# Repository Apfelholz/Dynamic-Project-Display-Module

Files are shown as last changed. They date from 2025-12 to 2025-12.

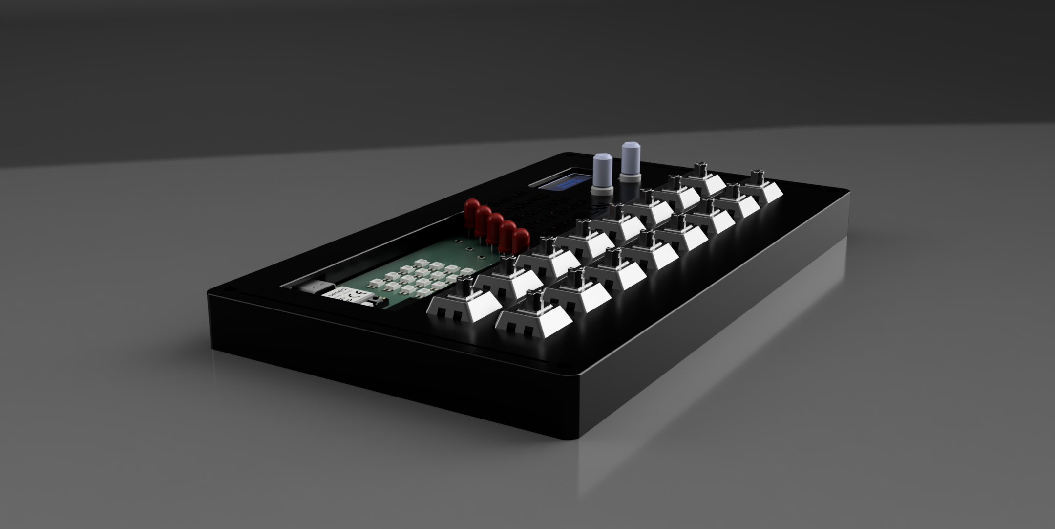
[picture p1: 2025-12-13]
CAD/Renders/DPDIM_V1_FrontLeft.png

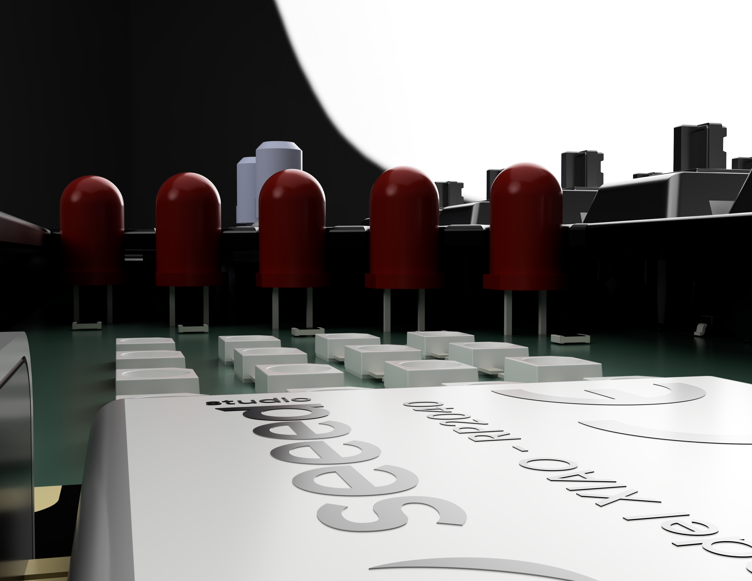
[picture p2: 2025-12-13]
CAD/Renders/DPDIM V1_Inside.png

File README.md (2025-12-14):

## Hi

I'm a young student from Germany who loves to program and also builds in the physical world from time to time. This project is the first time I ever worked on PCB design and produced a (serious) CAD model. 

When I found out about Blueprint I had already built an Arduino-based prototype of the idea that soon became this project. With the knollage of the requirements that I needed from this adventure I got to designing the DPDIM V1. (The first thing being finding some stupid acronym)

# Dynamic Project Display and Input Module

DPDIM is a 16-key micropad with a 4x4 RGB LED matrix, five status LEDs, an OLED display and two rotary encoders. It is based on the Seeed XIAO RP2040 and misuses KMK for the firmware.

## Features

- 16 keys for custom functionality
- 4x4 WS2812B RGB LED matrix as a simple and bright display option
- 128x32 OLED display
- 2 EC11 rotary encoders to get even more input options
- 5 status LEDs to get myself to do my work...

# CAD

The model includes a cutout for the USB and I2C connection in the back as well as a big one at the top to show some of the inside and the LED matrix. In the top plate there are also two decorative channels and the descriptions of the status LEDs. The keys are placed at the bottom for easy access when placed over the mouse on the desk. 

DPDIM V1_Inside

DPDIM_V1_FrontLeft

DPDIM_V1_FrontTop

The model has been made in Fusion 360 after Onshape did collapse on me. 

# PCB

The PCB design I did in KiCad while learning the software on the fly. The silkscreen picture is an experiment I don't expect to work but took the chance to test. 

Schematic: 

WhatsApp Bild 2025-12-07 um 17.29.00_7e5e3bc0

PCB:

WhatsApp Bild 2025-12-07 um 17.28.47_4aa92623

# Firmware

The firmware implements a JSON API that is able to be controlled from the PC. As I don't have the pad yet it is untested. 

The exact API layout:

### 1. LED Control

Control individual status LEDs.

**Command:**
```json
{
  "type": "led",
  "index": 0,
  "value": true
}
```

**Parameters:**
- `type` (string): `"led"`
- `index` (integer): LED index
- `value` (boolean): `true` = ON, `false` = OFF

### 2. RGB Pixel Control (Single)

**Command:**
```json
{
  "type": "rgb",
  "index": 5,
  "r": 255,
  "g": 128,
  "b": 0
}
```

**Parameters:**
- `type` (string): `"rgb"`
- `index` (integer): Pixel index
- `r` (integer)
- `g` (integer)
- `b` (integer)

### 3. RGB Pixel Control (All)

**Command:**
```json
{
  "type": "rgb_all",
  "r": 255,
  "g": 0,
  "b": 0
}
```

**Parameters:**
- `type` (string): `"rgb_all"`
- `r` (integer)
- `g` (integer)
- `b` (integer)

### 4. OLED Display - Set Text

**Command:**
```json
{
  "type": "oled",
  "line": 0,
  "text": "Hello World"
}
```

**Parameters:**
- `type` (string): `"oled"`
- `line` (integer): Line index
- `text` (string)

### 5. OLED Display - Clear All

**Command:**
```json
{
  "type": "oled_clear"
}
```

**Parameters:**
- `type` (string): `"oled_clear"`

## Events (Device → Host)

### 1. Key Press/Release

**Message:**
```json
{
  "type": "key",
  "row": 0,
  "col": 5,
  "state": "press"
}
```

**Fields:**
- `type` (string): `"key"`
- `row` (integer): Row index (0-1)
- `col` (integer): Column index (0-8)
- `state` (string): `"press"` or `"release"`

---

### 2. Encoder Rotation

**Message:**
```json
{
  "type": "encoder",
  "id": 0,
  "delta": 1
}
```

**Fields:**
- `type` (string): `"encoder"`
- `id` (integer)
- `delta` (integer): Direction: `1` = clockwise, `-1` = counter-clockwise

### 3. Encoder Button

**Message:**
```json
{
  "type": "encoder_btn",
  "id": 0,
  "state": "press"
}
```

**Fields:**
- `type` (string): `"encoder_btn"`
- `id` (integer)
- `state` (string): `"press"` or `"release"`

## Response Types

### Acknowledgment (ACK)

Sent when a command is successfully executed.

**Format:**
```json
{
  "type": "ack",
  "cmd": "led"
}
```

**Fields:**
- `type` (string): `"ack"`
- `cmd` (string): The command type that was executed

### Error

Sent when a command fails.

**Format:**
```json
{
  "type": "err",
  "cmd": "rgb",
  "reason": "bad_args"
}
```

**Fields:**
- `type` (string): `"err"`
- `cmd` (string): The command type that failed
- `reason` (string): Error reason:
  - `"json"` - JSON parsing error
  - `"bad_args"` - Invalid arguments or out-of-range values
  - `"unknown_cmd"` - Unknown command type

# BOM 

In BOM.csv

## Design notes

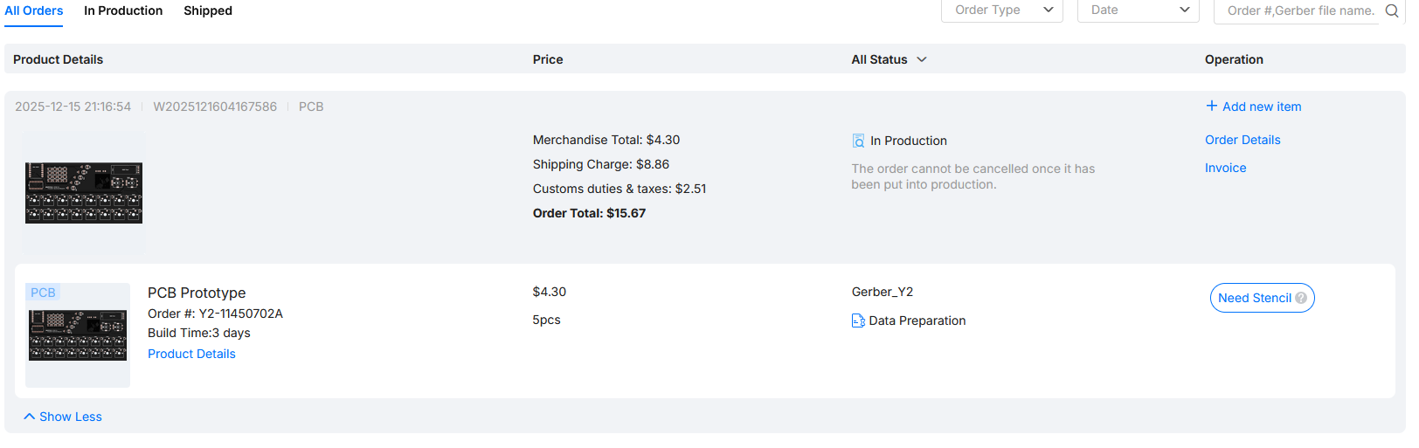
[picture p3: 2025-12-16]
JLCPCB.png

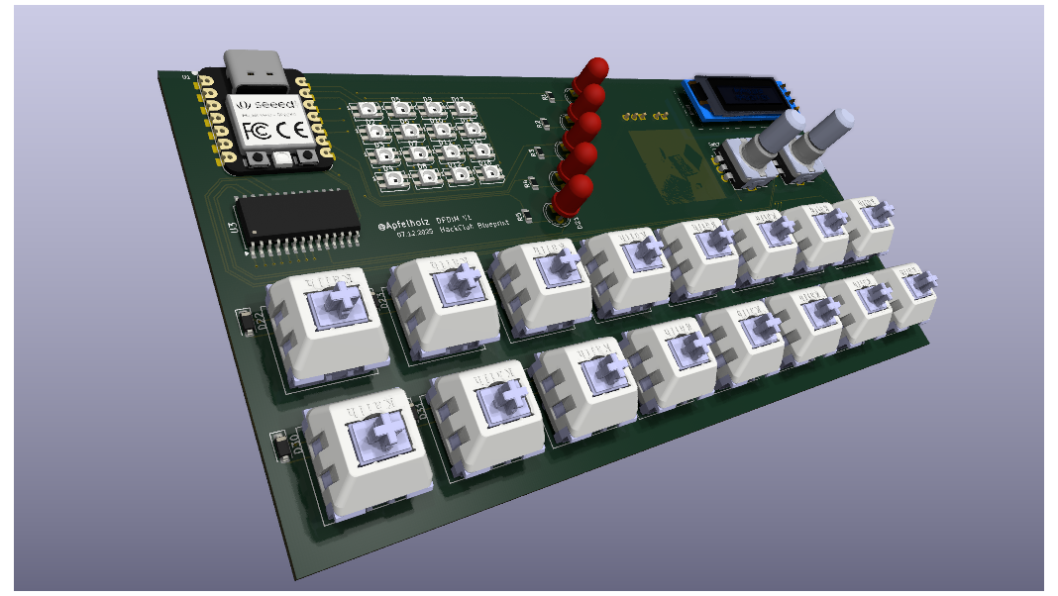
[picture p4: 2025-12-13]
CAD/Renders/KiCad-Diynamic-Project-Display-Module.png

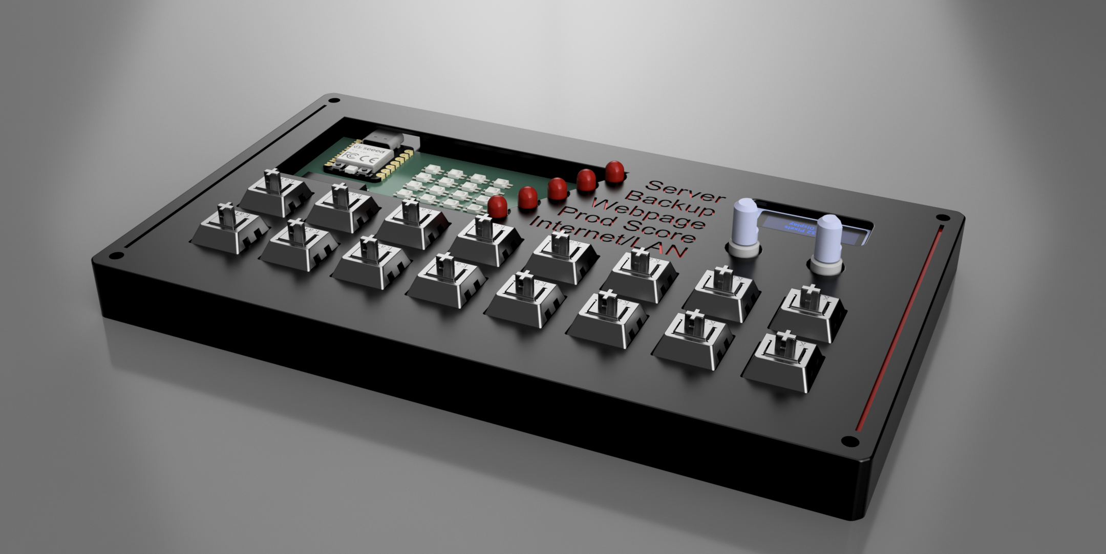
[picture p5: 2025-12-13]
CAD/Renders/DPDIM V1_FrontRight.png

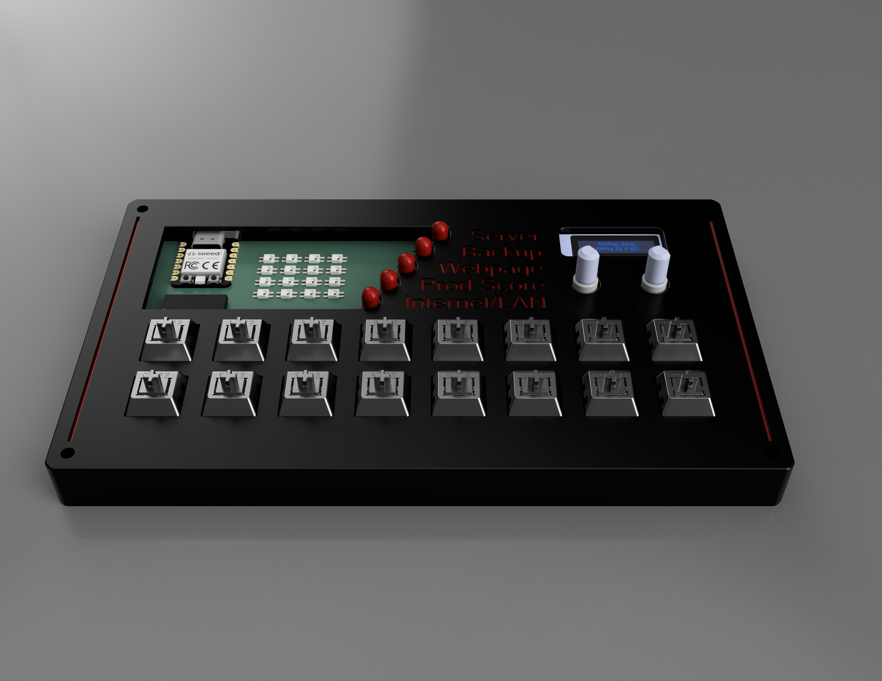
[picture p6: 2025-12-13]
CAD/Renders/DPDIM_V1_FrontTop.png

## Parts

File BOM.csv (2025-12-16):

KICad BOM
ID | Bezeichner | Footprint | Stückzahl | Bezeichnung | Link | Unit Price (€) | Total Price (€)
1 | R5,R3,R4,R1,R2 | R_0805_2012Metric_Pad1.20x1.40mm_HandSolder | 5 | 200R | https://de.aliexpress.com/item/1005003413960273.html?curPageLogUid=BFyG77zEiabK | - | 4,04
2 | SW3,SW6,SW2,SW16,SW10,SW14,SW12,SW8,SW7,SW5,SW13,SW9,SW4,SW11,SW1,SW15 | SW_Cherry_MX_1.00u_PCB | 16 | SW_Push | https://www.reichelt.de/de/de/shop/produkt/cherry_mx_blue_-_tastenmodul_-_fixierzapfen-369269 | provided
3 | D37,D24,D34,D28,D31,D22,D23,D32,D30,D27,D39,D33,D35,D29,D26,D36,D25,D38 | D_SOD-123 | 18 | D | https://de.aliexpress.com/item/1005007118972345.html?curPageLogUid=9GncDW1vCwrk | - | 3,64
4 | D9,D12,D1,D13,D2,D14,D8,D16,D3,D11,D15,D5,D7,D4,D10,D6 | LED_SK6812MINI_PLCC4_3.5x3.5mm_P1.75mm | 16 | SK6812MINI | https://de.aliexpress.com/item/1005007863635868.html?curPageLogUid=uiXVLImmVGYQ | provided
6 | Brd1 | SSD1306-0.91-OLED-4pin-128x32 | 1 | GME12864_OLED | https://de.aliexpress.com/item/1005008640108394.html?curPageLogUid=75kDP72p1P9Y | provided
7 | U1 | XIAO-RP2040-DIP | 1 | XIAO-RP2040-DIP | https://de.aliexpress.com/item/1005003683887126.html?curPageLogUid=iyNb21ibwtPA | provided
8 | SW17,SW18 | RotaryEncoder_Alps_EC11E-Switch_Vertical_H20mm_MountingHoles | 2 | RotaryEncoder_Switch_MP | https://de.aliexpress.com/item/1005008583446552.html?curPageLogUid=sLxNjNwPbA56 | provided
9 | U3 | SOIC-28W_7.5x17.9mm_P1.27mm | 1 | MCP23017_SO | https://de.aliexpress.com/item/1005009034247985.html?curPageLogUid=r1iDWc1KUoAc | - | 6,64
10 | J2 | PinHeader_1x02_P2.54mm_Horizontal | 1 | Conn_01x02_Pin | https://de.aliexpress.com/item/32963604292.html?curPageLogUid=C4FsHZ2x8Ltg | - | 0,99
11 | J1 | PinHeader_1x03_P2.54mm_Horizontal | 1 | Conn_01x03_Pin | https://de.aliexpress.com/item/32963604292.html?curPageLogUid=C4FsHZ2x8Ltg | - | 0,99
 |  |  | 4 | M3 14mm | https://www.aliexpress.com/ssr/300000512/BundleDeals2?productIds=1005005070119421:12000031519353305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 | provided
 |  |  | 4 | M3 4mmx5mm inserts | https://de.aliexpress.com/item/4000232858343.html?gatewayAdapt=usa2deu4itemAdapt | provided
 |  |  | 1 | PCB |  | 13,01 | 13,01
 |  |  | 16 | DSA keycaps |  | provided
 |  |  | 1 | USB Cabal | https://de.aliexpress.com/item/1005007431063094.html?mp=1 | 0,99 | 0,99
 |  |  |  |  |  | Total: | 30,3
 |  |  |  |  |  |  | 17,29

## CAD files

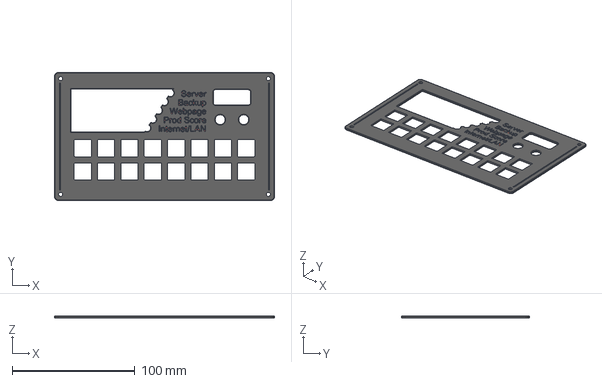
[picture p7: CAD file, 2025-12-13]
CAD/TopCase.step
179.5 x 104.4 x 1.50 mm

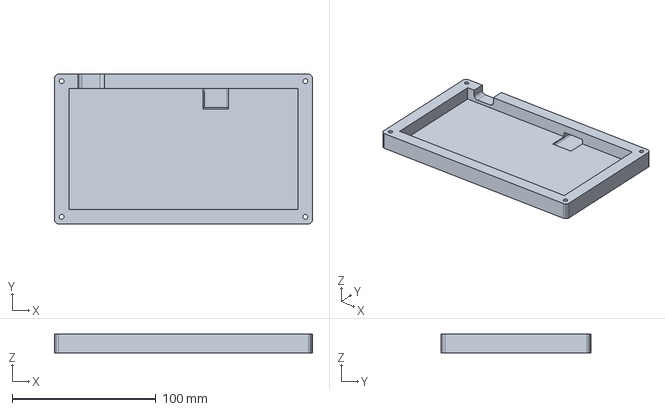
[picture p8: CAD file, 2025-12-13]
CAD/BottemCase.step
179.5 x 104.4 x 13.0 mm

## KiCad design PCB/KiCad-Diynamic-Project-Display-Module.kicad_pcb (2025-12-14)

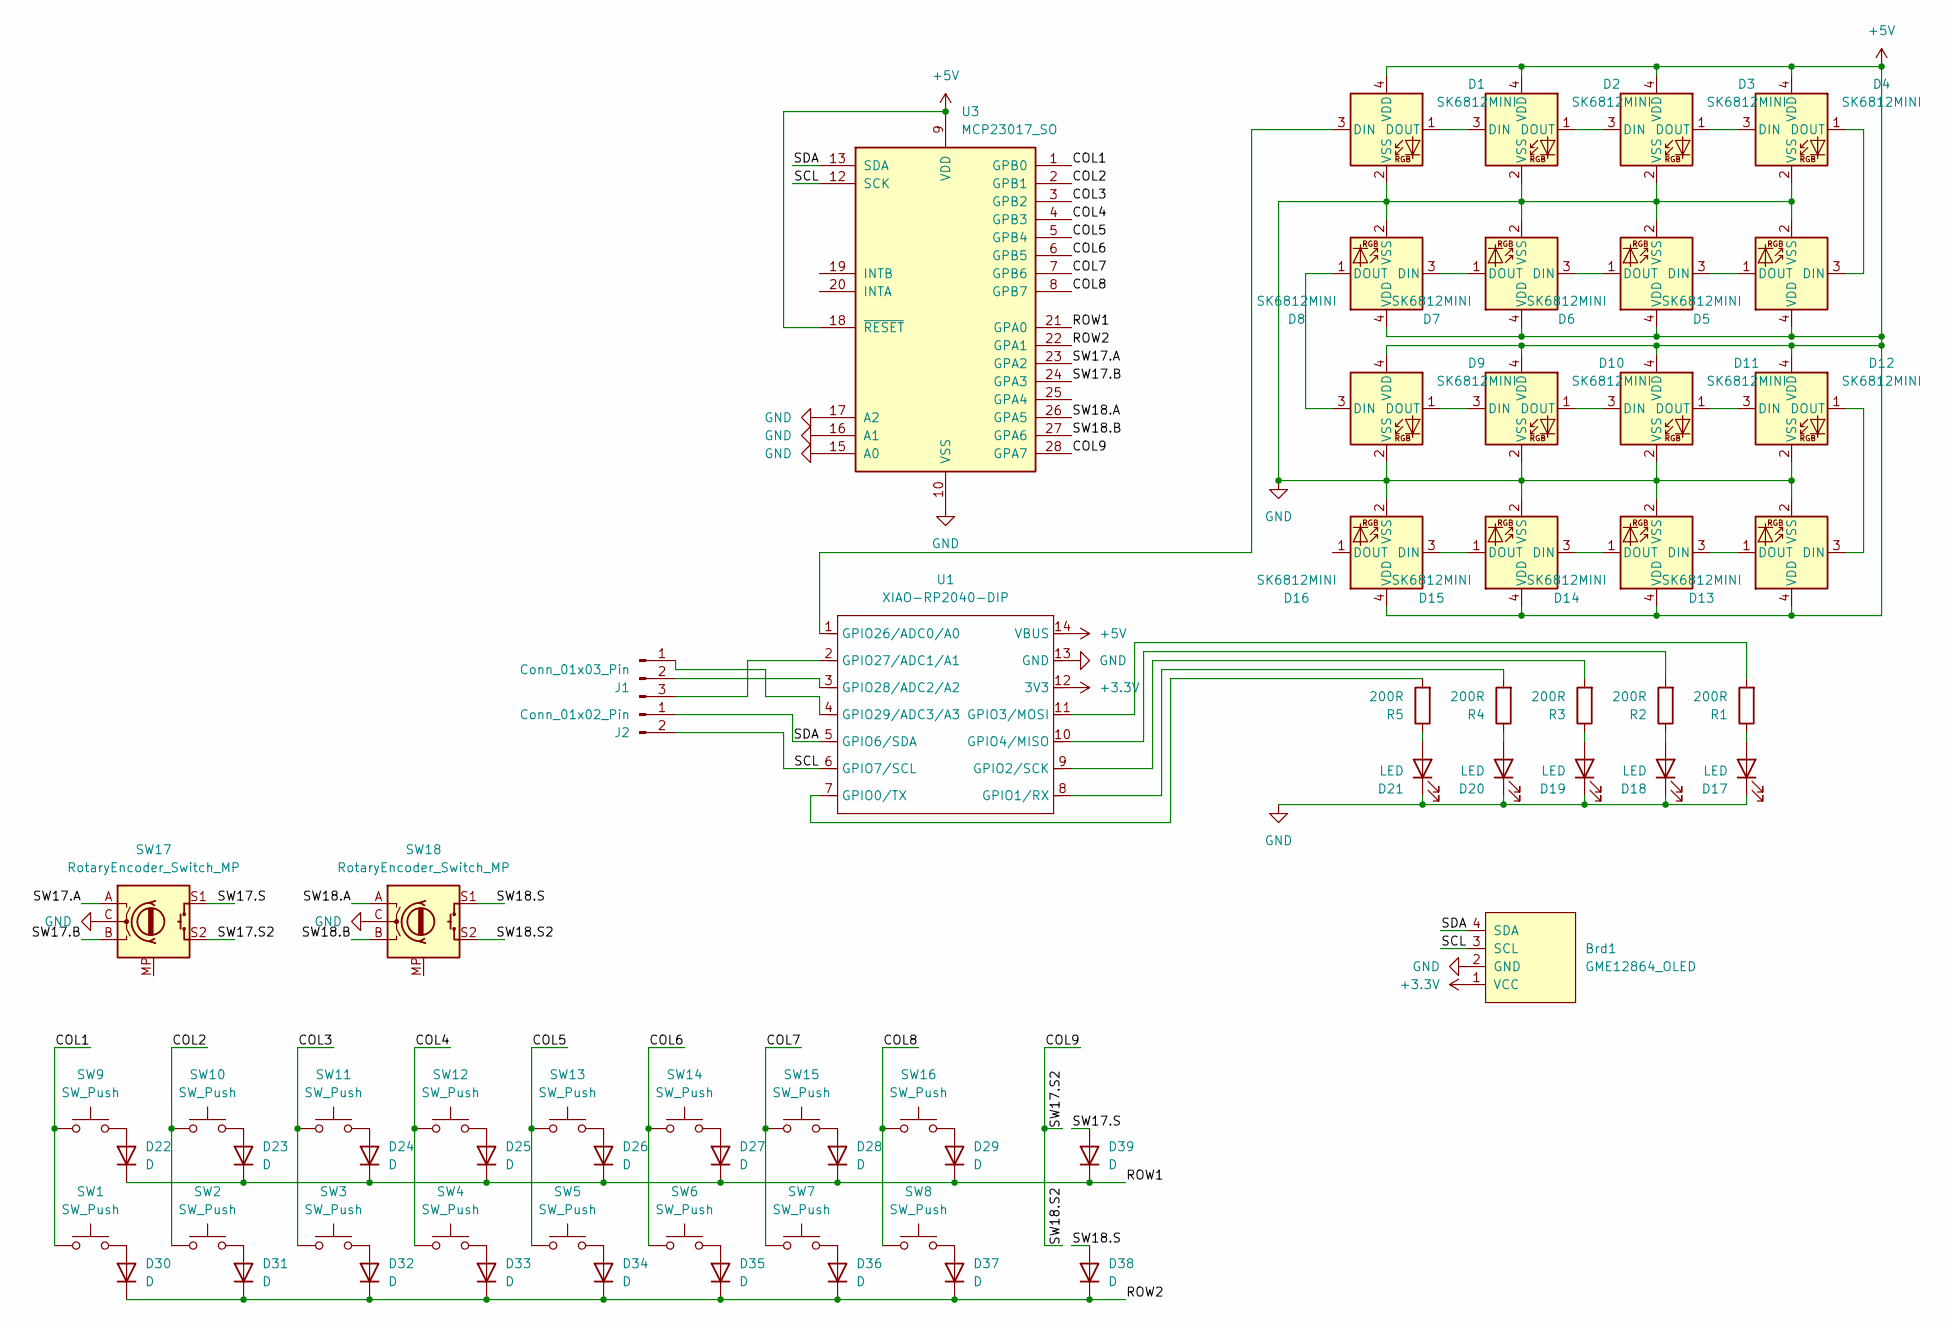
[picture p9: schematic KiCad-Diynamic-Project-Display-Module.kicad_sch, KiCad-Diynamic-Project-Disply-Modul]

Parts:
Brd1: GME12864_OLED; SSD1306-0.91-OLED-4pin-128x32
D1, D2, D3, D4, D5, D6, D7, D8, D9, D10, D11, D12, D13, D14, D15, D16: SK6812MINI; LED_SK6812MINI_PLCC4_3.5x3.5mm_P1.75mm
D17, D18, D19, D20, D21: LED; LED_D5.0mm
D22, D23, D24, D25, D26, D27, D28, D29, D30, D31, D32, D33, D34, D35, D36, D37, D38, D39: D; D_SOD-123
J1: Conn_01x03_Pin; PinHeader_1x03_P2.54mm_Horizontal
J2: Conn_01x02_Pin; PinHeader_1x02_P2.54mm_Horizontal
R1, R2, R3, R4, R5: 200R; R_0805_2012Metric_Pad1.20x1.40mm_HandSolder
SW1, SW2, SW3, SW4, SW5, SW6, SW7, SW8, SW9, SW10, SW11, SW12, SW13, SW14, SW15, SW16: SW_Push; SW_Cherry_MX_1.00u_PCB
SW17, SW18: RotaryEncoder_Switch_MP; RotaryEncoder_Alps_EC11E-Switch_Vertical_H20mm_MountingHoles
U1: XIAO-RP2040-DIP
U3: MCP23017_SO; SOIC-28W_7.5x17.9mm_P1.27mm

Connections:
+3.3V: Brd1.1 (VCC), U1.12 (3V3)
+5V: D1.4 (VDD), D2.4 (VDD), D3.4 (VDD), D4.4 (VDD), D5.4 (VDD), D6.4 (VDD), D7.4 (VDD), D8.4 (VDD), D9.4 (VDD), D10.4 (VDD), D11.4 (VDD), D12.4 (VDD), D13.4 (VDD), D14.4 (VDD), D15.4 (VDD), D16.4 (VDD), U1.14 (VBUS), U3.9 (VDD), U3.18 (~RESET)
/COL1: SW1.1, SW9.1, U3.1 (GPB0)
/COL2: SW2.1, SW10.1, U3.2 (GPB1)
/COL3: SW3.1, SW11.1, U3.3 (GPB2)
/COL4: SW4.1, SW12.1, U3.4 (GPB3)
/COL5: SW5.1, SW13.1, U3.5 (GPB4)
/COL6: SW6.1, SW14.1, U3.6 (GPB5)
/COL7: SW7.1, SW15.1, U3.7 (GPB6)
/COL8: SW8.1, SW16.1, U3.8 (GPB7)
/COL9: SW17.S2, SW18.S2, U3.28 (GPA7)
/ROW1: D22.1 (K), D23.1 (K), D24.1 (K), D25.1 (K), D26.1 (K), D27.1 (K), D28.1 (K), D29.1 (K), D39.1 (K), U3.21 (GPA0)
/ROW2: D30.1 (K), D31.1 (K), D32.1 (K), D33.1 (K), D34.1 (K), D35.1 (K), D36.1 (K), D37.1 (K), D38.1 (K), U3.22 (GPA1)
/SCL: Brd1.3 (SCL), J2.2, U1.6 (GPIO7/SCL), U3.12 (SCK)
/SDA: Brd1.4 (SDA), J2.1, U1.5 (GPIO6/SDA), U3.13 (SDA)
/SW17.A: SW17.A, U3.23 (GPA2)
/SW17.B: SW17.B, U3.24 (GPA3)
/SW17.S: D39.2 (A), SW17.S1
/SW18.A: SW18.A, U3.26 (GPA5)
/SW18.B: SW18.B, U3.27 (GPA6)
/SW18.S: D38.2 (A), SW18.S1
GND: Brd1.2 (GND), D1.2 (VSS), D2.2 (VSS), D3.2 (VSS), D4.2 (VSS), D5.2 (VSS), D6.2 (VSS), D7.2 (VSS), D8.2 (VSS), D9.2 (VSS), D10.2 (VSS), D11.2 (VSS), D12.2 (VSS), D13.2 (VSS), D14.2 (VSS), D15.2 (VSS), D16.2 (VSS), D17.1 (K), D18.1 (K), D19.1 (K), D20.1 (K), D21.1 (K), SW17.C, SW18.C, U1.13 (GND), U3.10 (VSS), U3.15 (A0), U3.16 (A1), U3.17 (A2)
unnamed: D1.3 (DIN), U1.1 (GPIO26/ADC0/A0)
unnamed: D1.1 (DOUT), D2.3 (DIN)
unnamed: D2.1 (DOUT), D3.3 (DIN)
unnamed: D3.1 (DOUT), D4.3 (DIN)
unnamed: D4.1 (DOUT), D5.3 (DIN)
unnamed: D5.1 (DOUT), D6.3 (DIN)
unnamed: D6.1 (DOUT), D7.3 (DIN)
unnamed: D7.1 (DOUT), D8.3 (DIN)
unnamed: D8.1 (DOUT), D9.3 (DIN)
unnamed: D9.1 (DOUT), D10.3 (DIN)
unnamed: D10.1 (DOUT), D11.3 (DIN)
unnamed: D11.1 (DOUT), D12.3 (DIN)
unnamed: D12.1 (DOUT), D13.3 (DIN)
unnamed: D13.1 (DOUT), D14.3 (DIN)
unnamed: D14.1 (DOUT), D15.3 (DIN)
unnamed: D15.1 (DOUT), D16.3 (DIN)
unnamed: D17.2 (A), R1.1
unnamed: D18.2 (A), R2.1
unnamed: D19.2 (A), R3.1
unnamed: D20.2 (A), R4.1
unnamed: D21.2 (A), R5.1
unnamed: D22.2 (A), SW9.2
unnamed: D23.2 (A), SW10.2
unnamed: D24.2 (A), SW11.2
unnamed: D25.2 (A), SW12.2
unnamed: D26.2 (A), SW13.2
unnamed: D27.2 (A), SW14.2
unnamed: D28.2 (A), SW15.2
unnamed: D29.2 (A), SW16.2
unnamed: D30.2 (A), SW1.2
unnamed: D31.2 (A), SW2.2
unnamed: D32.2 (A), SW3.2
unnamed: D33.2 (A), SW4.2
unnamed: D34.2 (A), SW5.2
unnamed: D35.2 (A), SW6.2
unnamed: D36.2 (A), SW7.2
unnamed: D37.2 (A), SW8.2
unnamed: J1.1, U1.4 (GPIO29/ADC3/A3)
unnamed: J1.2, U1.3 (GPIO28/ADC2/A2)
unnamed: J1.3, U1.2 (GPIO27/ADC1/A1)
unnamed: R5.2, U1.7 (GPIO0/TX)
unnamed: R4.2, U1.8 (GPIO1/RX)
unnamed: R3.2, U1.9 (GPIO2/SCK)
unnamed: R1.2, U1.11 (GPIO3/MOSI)
unnamed: R2.2, U1.10 (GPIO4/MISO)

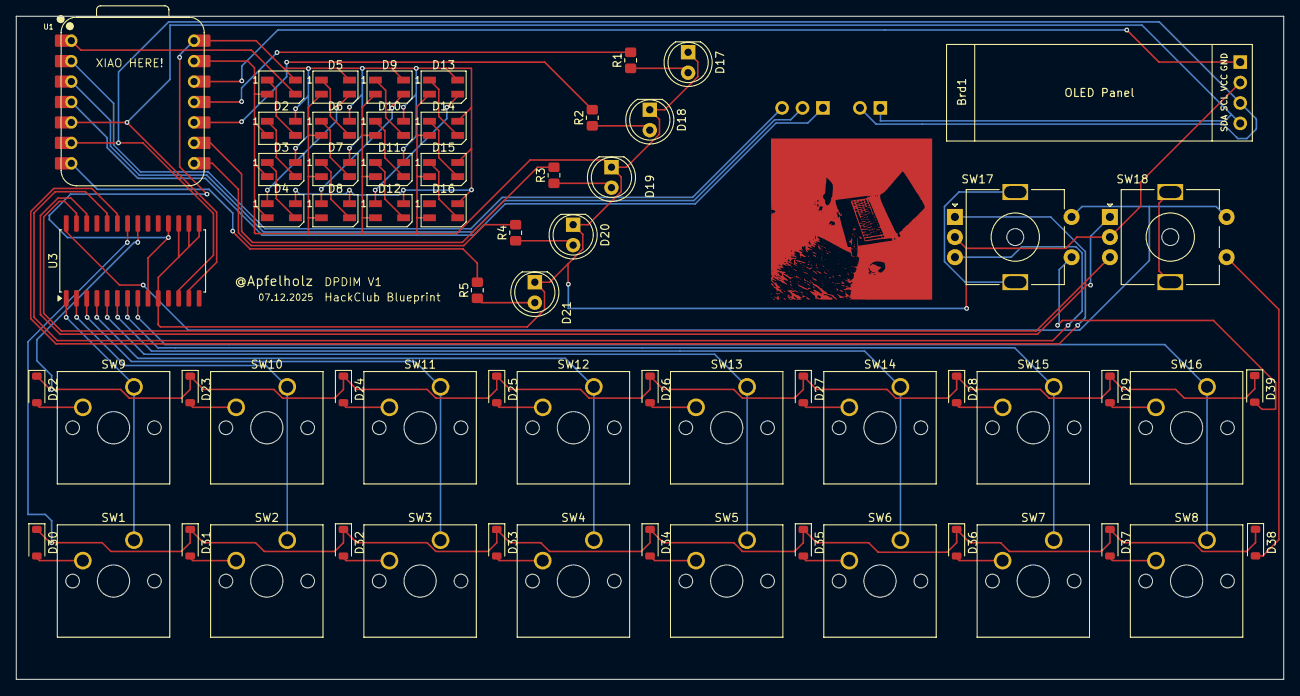
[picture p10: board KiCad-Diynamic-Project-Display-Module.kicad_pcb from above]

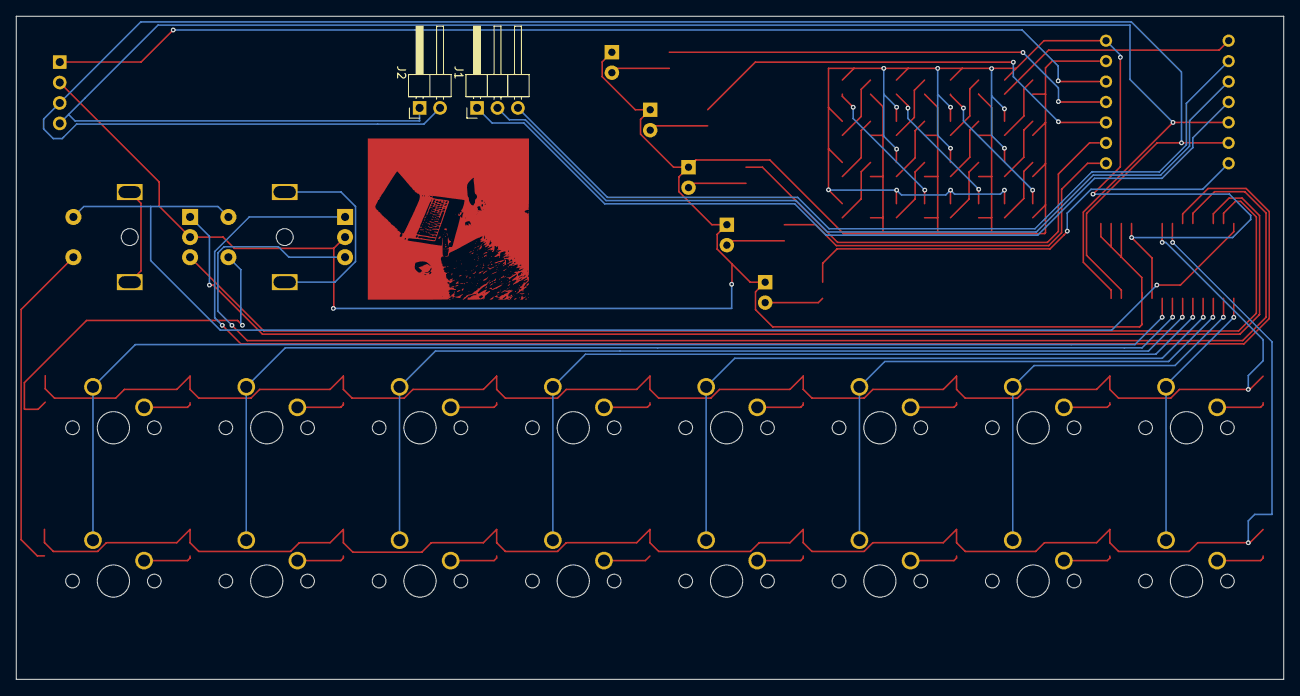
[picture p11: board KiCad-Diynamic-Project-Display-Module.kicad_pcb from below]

Board: 2 copper layers, 157.5 x 82.4 mm, 67 parts (2 on the bottom side), 67 nets.

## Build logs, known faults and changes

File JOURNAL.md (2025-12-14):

# Hi

Hey, I’m a young student from Germany who found out about the Hack Club a few hours ago XD. Since then, I have been using every second to start building a project I’ve had in mind forever.

# The Project

In a very similar fashion to the "Hackpad" guide, I have been dreaming of a hardware interface on my desk for the projects I build (and to check if my backup is live, just to calm some nerves…). As I have discovered, I have not been able to fit my plans into the constraints of the Hackpad guide. But if you look at the plan, it becomes clear that it has provided some inspiration. Despite this, the original idea is already a few weeks old. In these weeks, I have already built an Arduino-based prototype to test some of the functionality.

As I developed the idea today, I made a simple analog draft of the layout:

WhatsApp Bild 2025-12-06 um 00.24.01_b16f0518

I have come as far as to start learning KiCad, which I, as a programmer and developer in software, have never touched before. In this process, I have started to lay out the components: 

grafik

---

The last few hours I’ve been working on the schematic without a relay, having no idea what I was doing… XD

With the information from the provided guides and a bit of research, I was able to put together a version that 🤞 should work. To verify this, I’ve put a post up in Slack.

grafik

This schematic implements every part that I thought of in the drawing yesterday. To make this work, I had to use an IO expander, even though I didn’t really know how to do that. The next step toward completion will be to verify the correct implementation of this...

---

Today I started by finishing the schematic. Most of the work ended up being a fight with the libraries to get the right OLED and a matching footprint…

This change came from the message that was sent in Slack yesterday.

WhatsApp Bild 2025-12-07 um 17.29.00_7e5e3bc0

After finally completing the schematic, I moved on to the PCB.

The layout wasn’t much of a challenge. I had already done most of the thinking while sketching the first layout by hand (as shown in the entries below), so cleaning up the automatic placement only took a few minutes.

With that done, I started routing the PCB, taking extra care to make the traces look nice and to leave enough room for the silkscreen in the areas where the board will be visible in the end.

Even though I’ve never done anything like this before, I didn’t really run into problems and got everything done in a reasonable amount of time once I figured out the controls.

(And then I played around with the silkscreen…)

WhatsApp Bild 2025-12-07 um 17.28.47_4aa92623

Just to be sure, I posted the result on Slack to check if I messed anything up.

---

## There is a Case!?

DPDIM V1_FrontRight

In the time since the last journal, I have finished the hardware. On the PCB there were a few small errors, which the slack helped me correct, and I also spent some time cleaning up the routing while adding pins for future expansion. I also took the time to get 3D models for all the components to make designing the case easier.

KiCad-Diynamic-Project-Display-Module

I started designing the case in the Onshape cloud. This, as it turned out, wasn’t my brightest idea, as it took an eternity to even rotate the part, which was especially irritating while learning the controls on the fly. This caused me to give up on the program entirely and forced me to wait a few hours to get my Fusion 360 license.

After getting back to work with the processing power of my local machine, I didn’t have many problems creating a usable case, as I have prior experience with (very) simple CAD design.

My design is fairly simple, including only two “unconventional” features. The first is a large cutout that provides a view of the LED array, and the second is a cutout in the back that gives access to the expansion pins.

After getting a usable design, I added a few simple artistic elements to pimp it up and build something I actually want to have on my desk all the time. These come in the form of a few small channels in the top plate that will be filled with colored inlays after printing (they are colored in the renders).

DPDIM V1_Inside

DPDIM_V1_FrontLeft

DPDIM_V1_FrontTop

In the next step, I will create the README and check if there is anything else to do before submitting.

---

In the last few hours I have been able to produce 171 lines of code, that in theory should get my board up and running.

The software architecture of my design incorporates two parts, that are working in sync. The first one is the firmware, which is based on KMK. It implements a JSON API on the serial bus which enables me to send inputs to the PC and receive status updates for the various display options. On the side of the PC there is a program, that is on auto start. It acts on the inputs and queries various sources of information locally, like my ActivityWatch localhost and the server and website. This information is sent to the pad to be displayed.

The exact API layout:

### 1. LED Control

Control individual status LEDs.

**Command:**
```json
{
  "type": "led",
  "index": 0,
  "value": true
}
```

**Parameters:**
- `type` (string): `"led"`
- `index` (integer): LED index
- `value` (boolean): `true` = ON, `false` = OFF

### 2. RGB Pixel Control (Single)

**Command:**
```json
{
  "type": "rgb",
  "index": 5,
  "r": 255,
  "g": 128,
  "b": 0
}
```

**Parameters:**
- `type` (string): `"rgb"`
- `index` (integer): Pixel index
- `r` (integer)
- `g` (integer)
- `b` (integer)

### 3. RGB Pixel Control (All)

**Command:**
```json
{
  "type": "rgb_all",
  "r": 255,
  "g": 0,
  "b": 0
}
```

**Parameters:**
- `type` (string): `"rgb_all"`
- `r` (integer)
- `g` (integer)
- `b` (integer)

### 4. OLED Display - Set Text

**Command:**
```json
{
  "type": "oled",
  "line": 0,
  "text": "Hello World"
}
```

**Parameters:**
- `type` (string): `"oled"`
- `line` (integer): Line index
- `text` (string)

### 5. OLED Display - Clear All

**Command:**
```json
{
  "type": "oled_clear"
}
```

**Parameters:**
- `type` (string): `"oled_clear"`

## Events (Device → Host)

### 1. Key Press/Release

**Message:**
```json
{
  "type": "key",
  "row": 0,
  "col": 5,
  "state": "press"
}
```

**Fields:**
- `type` (string): `"key"`
- `row` (integer): Row index (0-1)
- `col` (integer): Column index (0-8)
- `state` (string): `"press"` or `"release"`

---

### 2. Encoder Rotation

**Message:**
```json
{
  "type": "encoder",
  "id": 0,
  "delta": 1
}
```

**Fields:**
- `type` (string): `"encoder"`
- `id` (integer)
- `delta` (integer): Direction: `1` = clockwise, `-1` = counter-clockwise

### 3. Encoder Button

**Message:**
```json
{
  "type": "encoder_btn",
  "id": 0,
  "state": "press"
}
```

**Fields:**
- `type` (string): `"encoder_btn"`
- `id` (integer)
- `state` (string): `"press"` or `"release"`

## Response Types

### Acknowledgment (ACK)

Sent when a command is successfully executed.

**Format:**
```json
{
  "type": "ack",
  "cmd": "led"
}
```

**Fields:**
- `type` (string): `"ack"`
- `cmd` (string): The command type that was executed

### Error

Sent when a command fails.

**Format:**
```json
{
  "type": "err",
  "cmd": "rgb",
  "reason": "bad_args"
}
```

**Fields:**
- `type` (string): `"err"`
- `cmd` (string): The command type that failed
- `reason` (string): Error reason:
  - `"json"` - JSON parsing error
  - `"bad_args"` - Invalid arguments or out-of-range values
  - `"unknown_cmd"` - Unknown command type

As I don’t have my board yet, my only option is to pray this works...

(the same render als last time: I like it as the profile pic!)
DPDIM V1_FrontRight

---

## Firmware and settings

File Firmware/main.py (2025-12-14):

import json

import board
import busio
import digitalio
import usb_cdc
from kmk.extensions import Extension
from kmk.extensions.display import Display, TextEntry
from kmk.extensions.display.ssd1306 import SSD1306
from kmk.extensions.rgb import RGB
from kmk.kmk_keyboard import KMKKeyboard
from kmk.modules.encoder import EncoderHandler
from kmk.scanners import DiodeOrientation
from kmk.scanners.keypad import MatrixScanner
from kmk.scanners.mcp230xx import MCP23017


API_VERSION = "1.0"


keyboard = KMKKeyboard()
serial = usb_cdc.data


# I2C
i2c = busio.I2C(board.GP5, board.GP4)


# Matrix (MCP23017)
mcp = MCP23017(i2c=i2c, address=0x20)
ROWS = [board.GP26, board.GP27]
COLS = [mcp.get_pin(i) for i in range(9)]


keyboard.matrix = MatrixScanner(
    columns=COLS,
    rows=ROWS,
    diode_orientation=DiodeOrientation.COL2ROW,
)


keyboard.keymap = [[None] * 18]


# Status LEDs
status_leds = []
for pin in [board.GP17, board.GP18, board.GP19]:
    led = digitalio.DigitalInOut(pin)
    led.direction = digitalio.Direction.OUTPUT
    status_leds.append(led)


# RGB
rgb = RGB(pixel_pin=board.GP16, num_pixels=16, val_limit=120)
keyboard.extensions.append(rgb)


# OLED
display = Display(
    display=SSD1306(i2c=i2c),
    entries=[
        TextEntry(text="MacroPad", x=0, y=0),
        TextEntry(text="Ready", x=0, y=10),
    ],
)
keyboard.extensions.append(display)


# Encoder
encoder = EncoderHandler()
encoder.pins = ((board.GP10, board.GP11, board.GP12),)
keyboard.modules.append(encoder)


class JsonAPI(Extension):
    def send(self, obj):
        serial.write(json.dumps(obj).encode() + b"\n")

    def before_matrix_scan(self, keyboard):
        if serial.in_waiting:
            try:
                # serial.readline() returns bytes; decode before json parsing
                raw = serial.readline()
                msg = json.loads(raw.decode())
                self.handle_cmd(msg)
            except Exception:
                self.send({"type": "err", "cmd": "unknown", "reason": "json"})

    def handle_cmd(self, msg):
        t = msg.get("type")
        try:
            if t == "led":
                idx = int(msg.get("index", -1))
                val = bool(msg.get("value", False))
                if 0 <= idx < len(status_leds):
                    status_leds[idx].value = val
                else:
                    raise ValueError("bad_led_index")
            elif t == "rgb":
                idx = int(msg.get("index", -1))
                r = int(msg.get("r", 0))
                g = int(msg.get("g", 0))
                b = int(msg.get("b", 0))
                if 0 <= idx < rgb.num_pixels:
                    rgb.set_pixel(idx, (r, g, b))
                    rgb.show()
                else:
                    raise ValueError("bad_rgb_index")
            elif t == "rgb_all":
                r = int(msg.get("r", 0))
                g = int(msg.get("g", 0))
                b = int(msg.get("b", 0))
                for i in range(rgb.num_pixels):
                    rgb.set_pixel(i, (r, g, b))
                rgb.show()
            elif t == "oled":
                line = int(msg.get("line", -1))
                text = str(msg.get("text", ""))
                if 0 <= line < len(display.entries):
                    display.entries[line].text = text
                else:
                    raise ValueError("bad_oled_line")
            elif t == "oled_clear":
                for e in display.entries:
                    e.text = ""
            else:
                raise ValueError("unknown_cmd")


            self.send({"type": "ack", "cmd": t})


        except Exception:
            self.send({"type": "err", "cmd": t, "reason": "bad_args"})

    def on_key_event(self, keyboard, key, is_pressed):
        if key:
            self.send({
                "type": "key",
                "row": key.row,
                "col": key.col,
                "state": "press" if is_pressed else "release",
            })


    def on_encoder_turn(self, keyboard, encoder_id, direction):
        self.send({
            "type": "encoder",
            "id": encoder_id,
            "delta": direction,
        })


    def on_encoder_press(self, keyboard, encoder_id, is_pressed):
        self.send({
            "type": "encoder_btn",
            "id": encoder_id,
            "state": "press" if is_pressed else "release",
        })


keyboard.extensions.append(JsonAPI())


serial.write(json.dumps({
    "type": "boot",
    "api": API_VERSION,
    "status": "ready",
}).encode() + b"\n")

keyboard.go()

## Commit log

2025-12-05 the start of the scamatic
    [1_01 Table of Contents.kicad_sch, 2_02 Block Diagram.kicad_sch, 3_03 Power IN & MCU GPIOs.kicad_sch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]
2025-12-14 Add Tap Dance functionality and various scanner implementations
    - Introduced TapDanceKey and TapDance classes for enhanced key press handling.
    - Implemented MatrixScanner and RotaryioEncoder for key matrix and rotary encoder support.
    - Added KeypadScanner and its subclasses for different keypad configurations.
    - Created PIO_UART class for UART communication using PIO.
    - Added utility functions and debugging support in utils.py.
    - Established a main.py file to initialize the keyboard with I2C, matrix, RGB, OLED, and encoder support.
    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
2025-12-14 Enhance JsonAPI with error handling and additional commands for OLED and encoder interactions
    [main.py]
2025-12-14 Refactor code structure for improved readability and maintainability
    [KiCad-Diynamic-Project-Display-Module.csv, KiCad-Diynamic-Project-Display-Module.kicad_sch]
2025-12-14 change folder struckture to match recuerments
    [1_01 Table of Contents.kicad_sch, 2_02 Block Diagram.kicad_sch, 3_03 Power IN & MCU GPIOs.kicad_sch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]
2025-12-14 Refactor BOM.csv format for improved readability and consistency; add detailed project journal in JOURNAL.md; update README.md with new content.
    [BOM.csv]
2025-12-15 Refactor BOM.csv for improved formatting and readability; update component details and links.
    [BOM.csv]
2025-12-15 Update BOM.csv to include DSA keycaps and adjust total formatting for clarity
    [BOM.csv]
2025-12-16 add image of the shipping option and oubdate bom
    [BOM.csv]
